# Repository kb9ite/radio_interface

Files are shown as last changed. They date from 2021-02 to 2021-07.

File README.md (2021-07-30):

# Radio Interface
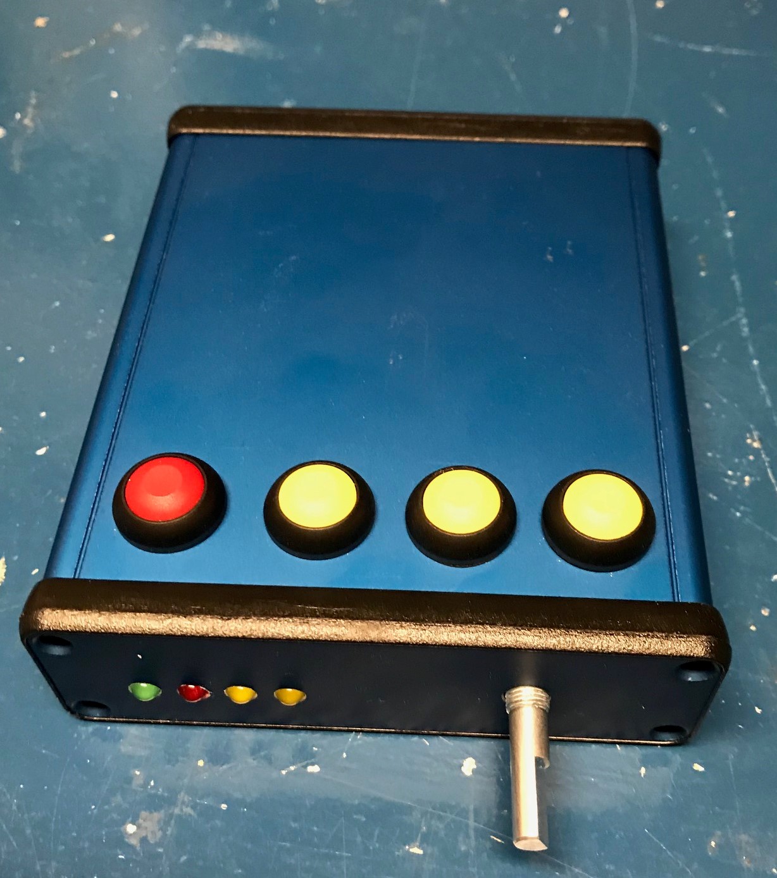
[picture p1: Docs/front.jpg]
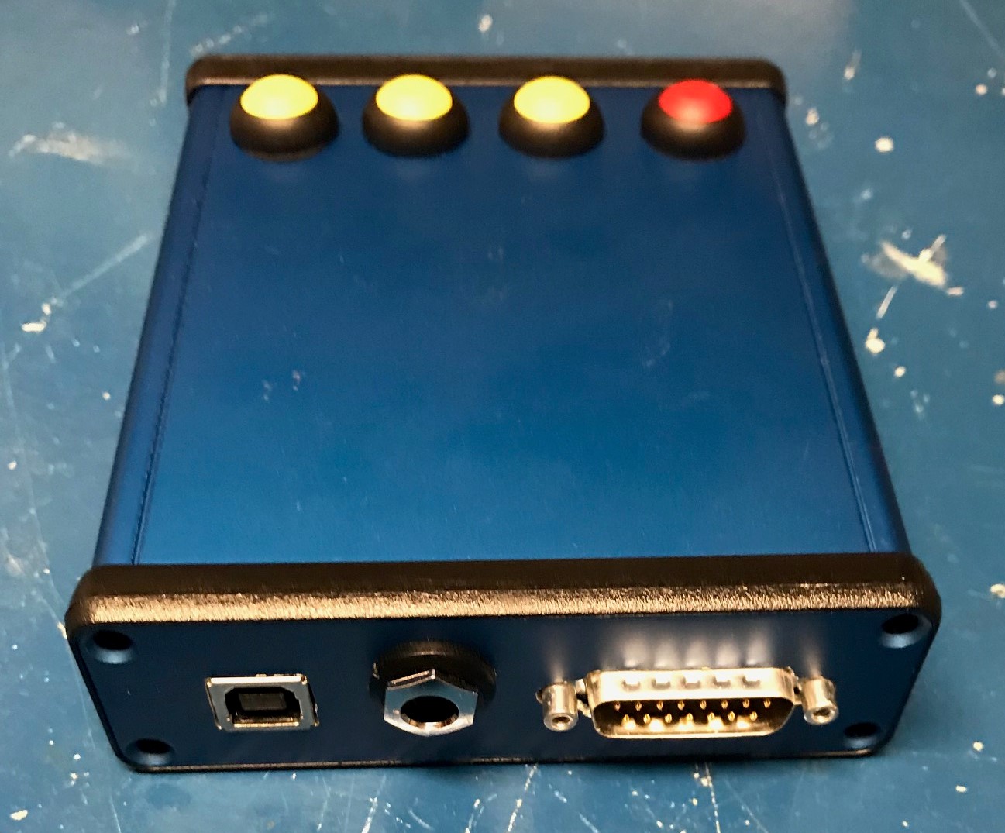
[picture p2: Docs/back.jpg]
  

## Introduction
I've been a ham for a while, growing up the son of a ham, I had a pretty nice setup readily available.  After some time away from the hobby I found myself getting back into it and starting to put together my own station.  I quickly realized I was going to want to interface the radio with the computer.  As I started to breakdown my needs I came up with the following:

 - Rx and Tx audio to run digital modes
 - PTT so I could avoid using Vox and transmitting computer sounds I shouldn't
 - FSK to dabble in RTTY
 - CW Key thinking I might learn morse code again
 - Serial so that I could get the bandmap working on my PC

Taking a look around there are a number of good options for off the shelf interfaces, although non had all the functionality I was looking for in one box.  Being a DIY kind of person (and frugal) and having some experience with PCB design and assembly I figured I would just build my own.  A little bit of searching around showed that there were single chip solutions for a USB sound card and I had already used USB to serial devices in previous projects.  Armed with that information I set out looking for a design to build.  I figured surely someone has shared a design where they through a USB hub, USB audio codec and USB to serial adapter on a single PCB, right?  All of my searching produced nothing, so I decided to design one myself.

This project represents the results of that effort.  It is a single box solution that includes a sound card, 2 serial ports, a WinKeyer and galvanic isolation between the radio and PCB.
## Design
The general design philosophy I used was to try and make the design flexible to be adapted to other people's uses without requiring PCB changes.  To that end there are some optional components and a jumper area for some configuring.

Starting with the computer end, the design includes a 3 port USB hub to allow a single USB connection to the PC.  This connects the audio coded (TI PCM2903C) and 2 USB to serial chips (FTDI FT231XS).

One of the serial ports is setup for communication with the radio.  A pair of digital isolators are used to provide galvanically isolated TTL level Rx, Tx, RTS and CTS signals.  If this is the desired output some jumpers can be installed and these signals will be at the radio connector.  If RS232 levels are needed there is provision for an RS232 level shifter or if an ICOM CI-V interface is needed there is space for a simple transistor to provide the open collector style single wire serial.  The polarity of the inputs/outputs on the serial interface can be changed using the FT_Prog utility from FTDI.

The second serial port allows control of an onboard WinKeyer3 IC from K1EL.  All the required peripherals to support the WinKeyer are included on board (speed pot, push button inputs and side tone speaker).

The audio support mono input/output.  By populating/depopulating a few parts the input/output channel can be changed as the PCM2903 is a stereo codec.  I built mine to just use left channel audio.  From the codec there is a second order low pass filter and then transformer for isolation.  On the radio side of the audio is provision for a fixed pad and a trimmer.  The fixed pad is intended to be used if a significant level shift is needed from line to mic or speaker to line levels.  The trimmer allows fine tuning of the levels to match the transceiver and computer.  The trimmer pots are inside the device so they are intended for a set it and forget it setup and regular fine tuning can be done either with radio controls (if available) or with the volume controls on the computer.

The outputs section supports up to 4 control outputs to the radio.  These can be used for whatever is desired (PTT, Key, FSK,...).  The outputs are designed to support either a optocoupler or reed relay for isolation of the outputs.  There is also the option of a front panel LED for each output to allow monitoring the output statuses.  The function of each output is selected through installing jumpers in the jumper area.  Signals available for the outputs include:

- All WinKeyer outputs (PTT1/2, Key 1/2)
- Both Serial Port (Tx, Rx, RTS, CTS, DTR)

The idea here is to make it easy for someone to build the box to his/her needs when building the device  by installing the desired set of jumpers on the prototyping connector.
|  |  |  |  |  |  |  |  |  |
|--|--|--|--|--|--|--|--|--|
|3-CAT_CTS|6-Out2Ctrl|9-Out4Ctrl|12-P1Key|15-P2PTT|18-Ser1_DTR|21-Ser1_CTS|24-Ser2_DTR|27-3.3V
|2-OutCom|5-CAT_Tx|8-Out3Ctrl|11-P1PTT|14-P2Key|17-Ser1_RTS|20-Ser2_Tx|23-Ser2_RTS|26-5V
|1-CAT_RTS|4-CAT_Rx|7-GND|10-Out1CTRL|13-Ser1_Tx|16-Ser1_Rx|19-Ser2_Rx|22-Ser2_CTS|25-GND

The interface to the radio is done with a DB15 connector.  The pinout is as follows:

 1. Rx Audio -
 2. Tx Audio -
 3. CAT_Rx
 4. CAT_CTS
 5. Out4
 6. Out3
 7. Out2
 8. Out1
 9. Rx Audio +
 10. Tx Audio +
 11. CAT_Tx
 12. CAT_RTS
 13. Out Common
 14. Out Common
 15. Out Common
 
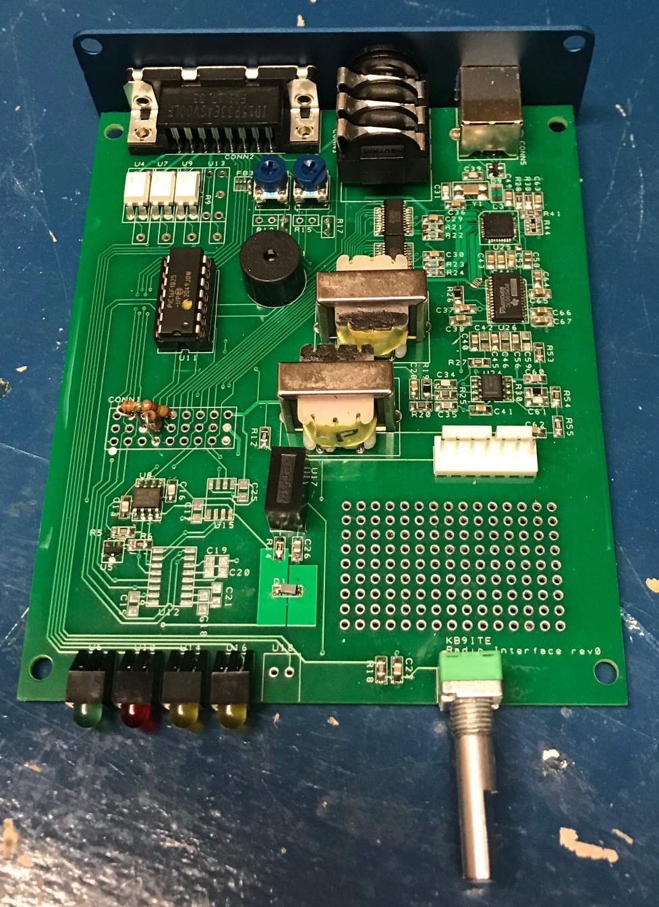
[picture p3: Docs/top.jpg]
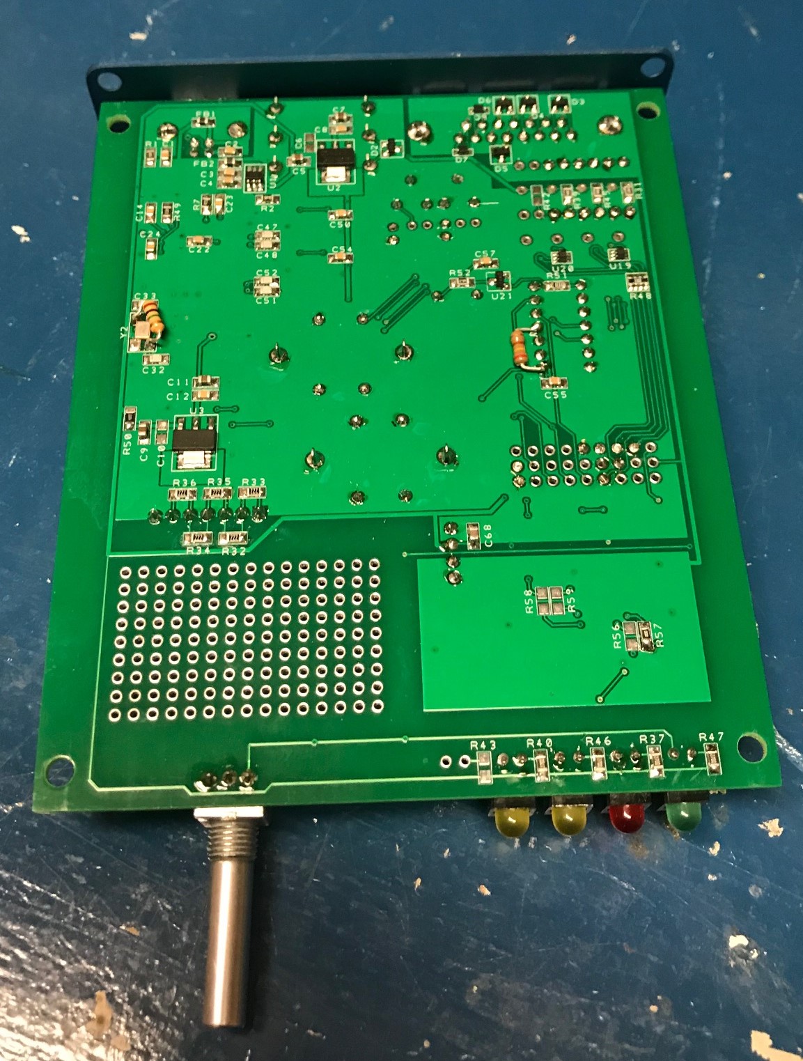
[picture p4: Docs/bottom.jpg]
   

## Tools
The schematic capture and PCB layout is all done with DesignSpark 9.0.
There is one device on the PCB that must be soldered with a hot air or reflowed and a couple of other that are easier that way, but could be done by hand.  Other than that most devices can be soldered by hand.

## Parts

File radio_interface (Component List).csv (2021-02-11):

Component List
--------------
Report Written: | Wednesday, February 10, 2021
Project Path: | C:\projects\radio_interface\DesignSpark\radio_interface.prj
Design Path: | C:\projects\radio_interface\DesignSpark\radio_interface.pcb
Design Title:
Created: | 1/28/2021 1:03:58 PM
Last Saved: | 2/10/2021 9:54:25 AM
Editing Time: | 19019 min
Units: | thou (precision 0)
Ref Name | Value | Manufacturer | Manufacturer Part Number | Digikey Number | Mouser Value
--------------------------------------------------------------------------------------------
C1 | 0.1u |  |  | 478-10836-1-ND | 581-08055C104KAT4A
C2 | 1n |  |  | 732-7813-1-ND | 187-CL21B102KBCNNNC
C3 | 1n |  |  | 732-7813-1-ND | 187-CL21B102KBCNNNC
C4 | 1u |  |  | 1276-1066-1-ND | 187-CL21B105KOFNNNG
C5 | 4.7u |  |  | 1276-6464-1-ND | 791-0805B475K6R3CT
C7 | 4.7u |  |  | 1276-6464-1-ND | 791-0805B475K6R3CT
C8 | 1n |  |  | 732-7813-1-ND | 187-CL21B102KBCNNNC
C9 | 4.7u |  |  | 1276-6464-1-ND | 791-0805B475K6R3CT
C11 | 4.7u |  |  | 1276-6464-1-ND | 791-0805B475K6R3CT
C12 | 1n |  |  | 732-7813-1-ND | 187-CL21B102KBCNNNC
C13 | 0.1u |  |  | 478-10836-1-ND | 581-08055C104KAT4A
C14 | 0.1u |  |  | 478-10836-1-ND | 581-08055C104KAT4A
C15 | 1u |  |  | 1276-1066-1-ND | 187-CL21B105KOFNNNG
C16 | 0.1u |  |  | 478-10836-1-ND | 581-08055C104KAT4A
C17 | 0.1u |  |  | 478-10836-1-ND | 581-08055C104KAT4A
C18 | 1u |  |  | 1276-1066-1-ND | 187-CL21B105KOFNNNG
C19 | 1u |  |  | 1276-1066-1-ND | 187-CL21B105KOFNNNG
C20 | 1u |  |  | 1276-1066-1-ND | 187-CL21B105KOFNNNG
C21 | 1u |  |  | 1276-1066-1-ND | 187-CL21B105KOFNNNG
C22 | 0.1u |  |  | 478-10836-1-ND | 581-08055C104KAT4A
C23 | 0.1u |  |  | 478-10836-1-ND | 581-08055C104KAT4A
C24 | 0.1u |  |  | 478-10836-1-ND | 581-08055C104KAT4A
C25 | 0.1u |  |  | 478-10836-1-ND | 581-08055C104KAT4A
C26 | 4.7u |  |  | 1276-6464-1-ND | 791-0805B475K6R3CT
C27 | 4.7n |  |  | 732-8037-1-ND | 710-885012207037
C28 | 10u |  |  | 1276-1096-1-ND | 187-CL21A106KQFNNNG
C29 | 0.1u |  |  | 478-10836-1-ND | 581-08055C104KAT4A
C30 | 0.1u |  |  | 478-10836-1-ND | 581-08055C104KAT4A
C31 | 12p |  |  | 311-1100-1-ND | 603-CC805JRNPO9BN120
C32 | 12p |  |  | 311-1100-1-ND | 603-CC805JRNPO9BN120
C33 | 12p |  |  | 311-1100-1-ND | 603-CC805JRNPO9BN120
C34 | 330p |  |  | 399-1130-1-ND | 80-C0805C331J5G
C35 | 1.8n |  |  | 445-5752-1-ND | 810-C2012C0G1H182J-1
C36 | 0.1u |  |  | 478-10836-1-ND | 581-08055C104KAT4A
C37 | 10u |  |  | 1276-1096-1-ND | 187-CL21A106KQFNNNG
C38 | 10u |  |  | 1276-1096-1-ND | 187-CL21A106KQFNNNG
C39 | 12p |  |  | 311-1100-1-ND | 603-CC805JRNPO9BN120
C40 | 10u |  |  | 1276-1096-1-ND | 187-CL21A106KQFNNNG
C41 | 10u |  |  | 1276-1096-1-ND | 187-CL21A106KQFNNNG
C43 | 0.1u |  |  | 478-10836-1-ND | 581-08055C104KAT4A
C44 | 0.1u |  |  | 478-10836-1-ND | 581-08055C104KAT4A
C45 | 10u |  |  | 1276-1096-1-ND | 187-CL21A106KQFNNNG
C47 | 47p |  |  | 311-1107-1-ND | 710-885012007014
C48 | 47p |  |  | 311-1107-1-ND | 710-885012007014
C49 | 0.1u |  |  | 478-10836-1-ND | 581-08055C104KAT4A
C50 | 0.1u |  |  | 478-10836-1-ND | 581-08055C104KAT4A
C51 | 47p |  |  | 311-1107-1-ND | 710-885012007014
C52 | 47p |  |  | 311-1107-1-ND | 710-885012007014
C53 | 0.1u |  |  | 478-10836-1-ND | 581-08055C104KAT4A
C54 | 0.1u |  |  | 478-10836-1-ND | 581-08055C104KAT4A
C55 | 0.1u |  |  | 478-10836-1-ND | 581-08055C104KAT4A
C56 | 10u |  |  | 1276-1096-1-ND | 187-CL21A106KQFNNNG
C57 | 0.1u |  |  | 478-10836-1-ND | 581-08055C104KAT4A
C58 | 4.7u |  |  | 1276-6464-1-ND | 791-0805B475K6R3CT
C60 | 1.8n |  |  | 445-5752-1-ND | 810-C2012C0G1H182J-1
C61 | 330p |  |  | 399-1130-1-ND | 80-C0805C331J5G
C62 | 10u |  |  | 1276-1096-1-ND | 187-CL21A106KQFNNNG
C63 | 0.1u |  |  | 478-10836-1-ND | 581-08055C104KAT4A
C64 | 10u |  |  | 1276-1096-1-ND | 187-CL21A106KQFNNNG
C65 | 10u |  |  | 1276-1096-1-ND | 187-CL21A106KQFNNNG
C66 | 10u |  |  | 1276-1096-1-ND | 187-CL21A106KQFNNNG
C67 | 10u |  |  | 1276-1096-1-ND | 187-CL21A106KQFNNNG
C68 | 4.7u |  |  | 1276-6464-1-ND | 791-0805B475K6R3CT
CONN2 |  |  | A-DF 15 A/KG-T2S | AE10929-ND | 649-ID15P33E4GV00LF
CONN3 |  |  | NMJ6HCD3 |  | 568-NMJ6HCD3
CONN4 |  |  |  |  | 538-22-23-2071
CONN5 |  |  | UJ2-BH-2-TH | 102-5884-ND | 490-UJ2-BH-2-TH
D1 | 5.1V |  |  |  | 771-PDZ5.1BGWX
D2 |  |  |  |  | 750-CPDT-5V0U
D3 |  |  |  |  | 750-CPDT-5V0U
D4 |  |  |  |  | 750-CPDT-5V0U
D5 |  |  |  |  | 750-CPDT-5V0U
D6 |  |  |  |  | 750-CPDT-5V0U
D7 |  |  | DESD5V0U1BA-7 |  | 621-DESD5V0U1BA-7
D8 |  |  | DESD5V0U1BA-7 |  | 621-DESD5V0U1BA-7
D9 |  |  | CM1213A-02SR | CM1213A-02SROSCT-ND | 748-CM1213A-02SR
FB1 |  |  |  | 490-1054-1-ND | 81-BLM21P221SG
FB2 |  |  |  | 490-1054-1-ND | 81-BLM21P221SG
FB3 |  |  | BK32164W241-T |  | 963-BK32164W241-T
L1 |  |  |  |  | 42TM018-RC
L2 |  |  |  |  | 42TM018-RC
R1 | 330 |  |  | A106061CT-ND | 754-RR1220P-331D
R2 | 604 |  |  | 311-604CRCT-ND | 603-RC0805FR-07604RL
R3 |  |  | 3570-1331-053 | 1835-1117-ND
R4 |  |  | 3570-1331-053 | 1835-1117-ND
R5 | 100k |  |  | 311-100KARCT-ND | 667-ERJ-6ENF1003V
R6 | 4.7k |  |  | A106065CT-ND | 71-CRCW08054K70FKEAC
R7 | 47k |  |  | A130144CT-ND | 279-CRGCQ0805J47K
R8 |  |  | 3570-1331-053 | 1835-1117-ND
R9 |  |  | 3570-1331-053 | 1835-1117-ND
R10
R11 | 2k |  | 3306F-1-202 |  | 652-3306F-1-202
R12 | 4.7k |  |  | A106065CT-ND | 71-CRCW08054K70FKEAC
R13
R14 | 20 |  |  |  | 667-ERJ-6ENF20R0V
R15
R16 | 2k |  | 3306F-1-202 |  | 652-3306F-1-202
R17
R18 | 470 |  |  | A129745CT-ND | 279-CRGCQ0805F470R
R19 | 3.9k |  |  | A126369CT-ND | 71-CRCW08053K90FKEA
R20 | 12k |  |  | A129762CT-ND | 279-CRGCQ0805F12K
R21 | 27 |  |  | 2019-RK73H2ATTD27R0FCT-ND | 660-RK73H2ATTD27R0F
R22 | 27 |  |  | 2019-RK73H2ATTD27R0FCT-ND | 660-RK73H2ATTD27R0F
R23 | 27 |  |  | 2019-RK73H2ATTD27R0FCT-ND | 660-RK73H2ATTD27R0F
R24 | 27 |  |  | 2019-RK73H2ATTD27R0FCT-ND | 660-RK73H2ATTD27R0F
R25 | 12k |  |  | A129762CT-ND | 279-CRGCQ0805F12K
R27 | 100 |  |  | A129737CT-ND | 279-CRGCQ0805F100R
R28 | 100k |  |  | 311-100KARCT-ND | 667-ERJ-6ENF1003V
R29 | 10k |  | P091N-FC25BR10K |  | 858-P091N-FC25BR10K
R30 | 3.9k |  |  | A126369CT-ND | 71-CRCW08053K90FKEA
R31 | 180 |  |  | A126343CT-ND | 667-ERJ-6ENF1800V
R32 | 2.2k |  |  | A106060CT-ND | 754-RR1220P-222D
R33 | 2.2k |  |  | A106060CT-ND | 754-RR1220P-222D
R34 | 2.2k |  |  | A106060CT-ND | 754-RR1220P-222D
R35 | 2.2k |  |  | A106060CT-ND | 754-RR1220P-222D
R36 | 2.2k |  |  | A106060CT-ND | 754-RR1220P-222D
R37 | 270 |  |  | A129742CT-ND | 279-CRGCQ0805F270R
R38 | 100k |  |  | 311-100KARCT-ND | 667-ERJ-6ENF1003V
R39 | 180 |  |  | A126343CT-ND | 667-ERJ-6ENF1800V
R40 | 270 |  |  | A129742CT-ND | 279-CRGCQ0805F270R
R41 | 100k |  |  | 311-100KARCT-ND | 667-ERJ-6ENF1003V
R42 | 180 |  |  | A126343CT-ND | 667-ERJ-6ENF1800V
R43 | 270 |  |  | A129742CT-ND | 279-CRGCQ0805F270R
R44 | 47k |  |  | Y9473CT-ND | 667-EXB-38V473JV
R45 | 180 |  |  | A126343CT-ND | 667-ERJ-6ENF1800V
R46 | 270 |  |  | A129742CT-ND | 279-CRGCQ0805F270R
R47 | 270 |  |  | A129742CT-ND | 279-CRGCQ0805F270R
R48 | 1k |  |  | Y9102CT-ND | 667-EXB-38V102JV
R49 | 47k |  |  | A130144CT-ND | 279-CRGCQ0805J47K
R50 | 4.7 |  |  |  | 71-RCG08054R70JNEA
R51 | 1k |  |  |  | 667-EXB-38V102JV
R52 | 68 |  |  |  | 667-ERJ-6ENF68R0V
R53 | 12k |  |  | A129762CT-ND | 279-CRGCQ0805F12K
R54 | 12k |  |  | A129762CT-ND | 279-CRGCQ0805F12K
R55 | 100 |  |  | A129737CT-ND | 279-CRGCQ0805F100R
SP1 |  |  | AT-1224-TWT-5V-R |  | 665-AT1224TWT5VR
U1 |  |  | MIC2009A-1YM6-TR |  | 998-MIC2009A-1YM6TR
U2 | 3.3V |  | AP2114H-3.3TRG1 | AP2114H-3.3TRG1DICT-ND | 621-AP2114H-3.3TRG1
U3 | 3.3V |  | AP2114H-3.3TRG1 | AP2114H-3.3TRG1DICT-ND | 621-AP2114H-3.3TRG1
U4 |  |  | 140816141310 | 732-140816141310-ND | 710-140816141310
U5 |  |  |  |  | 771-MMBT3904T/R
U6 |  |  | Y: LTL-553-11 R: | Y: 160-1978-ND, R: 160-1976-ND, G: 160-1977-ND | G: 859-LTL-533-11, R: 859-LTL-523-11, Y: 859-LTL-553-11
U7 |  |  | 140816141310 | 732-140816141310-ND | 710-140816141310
U8 |  |  | SI8621BC-B-IS |  | 634-SI8621BC-B-IS
U9 |  |  | 140816141310 | 732-140816141310-ND | 710-140816141310
U10 |  |  | Y: LTL-553-11 R: | Y: 160-1978-ND, R: 160-1976-ND, G: 160-1977-ND | G: 859-LTL-533-11, R: 859-LTL-523-11, Y: 859-LTL-553-11
U11 |  |  | WinKeyer
U12 |  |  | MAX232DR |  | 595-MAX232DR
U13 |  |  | 140816141310 | 732-140816141310-ND | 710-140816141310
U14 |  |  | Y: LTL-553-11 R: | Y: 160-1978-ND, R: 160-1976-ND, G: 160-1977-ND | G: 859-LTL-533-11, R: 859-LTL-523-11, Y: 859-LTL-553-11
U15 |  |  | SI8621BC-B-IS |  | 634-SI8621BC-B-IS
U16 |  |  | Y: LTL-553-11 R: | Y: 160-1978-ND, R: 160-1976-ND, G: 160-1977-ND | G: 859-LTL-533-11, R: 859-LTL-523-11, Y: 859-LTL-553-11
U17 |  |  | RFM-0505S |  | 919-RFM-0505S
U18 |  |  | Y: LTL-553-11 R: | Y: 160-1978-ND, R: 160-1976-ND, G: 160-1977-ND | G: 859-LTL-533-11, R: 859-LTL-523-11, Y: 859-LTL-553-11
U19 |  |  | SSM6N7002KFU,LF | SSM6N7002KFULFCT-ND | 757-SSM6N7002KFULF
U20 |  |  | SSM6N7002KFU,LF | SSM6N7002KFULFCT-ND | 757-SSM6N7002KFULF
U21 |  |  |  |  | 771-MMBT3904T/R
U22 |  |  | FT231XS-U | 768-1156-5-ND | 895-FT231XS-U
U23 |  |  | FT231XS-U | 768-1156-5-ND | 895-FT231XS-U
U24 |  |  | OPA1678IDR | 296-47347-1-ND | 595-OPA1678IDR
U25 |  |  | USB2513B/M2 | USB2513B/M2-ND | 579-USB2513B/M2
U26 |  |  | PCM2903CDBR | 296-34778-1-ND | 595-PCM2903CDBR
Y1 | 24MHz |  |  | 2151-RH100-24.000-10-1010-TRCT-ND | 669-EA2532UA12-24
Y2 | 12MHz |  |  | 2151-RH100-12.000-10-2020-EXT-TRCT-ND | 520-120-10-33-AGLT
--------------------------------------------------------------------------------------------

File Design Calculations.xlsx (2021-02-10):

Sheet: USB2513 XTAL
C0 | 3.5 | pF
CL | 10 | pF
CB |  | pF
CS1 | 0 | pF
CS2 | 0 | pF
CXTAL |  | pF
C1 | 13 | pF
C2 | 13 | pF

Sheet: Vreg thermal
Vin | 5 | V
Vout | 3.3 | V
I | 0.5 | A
Ploss | 0.85 | W
Rjunc_case | 50.9 | C/W
Tamb | 40 | C
Tmax | 150 | C
Rheat_sink | 78.51176471
 |  |  | t = R*P

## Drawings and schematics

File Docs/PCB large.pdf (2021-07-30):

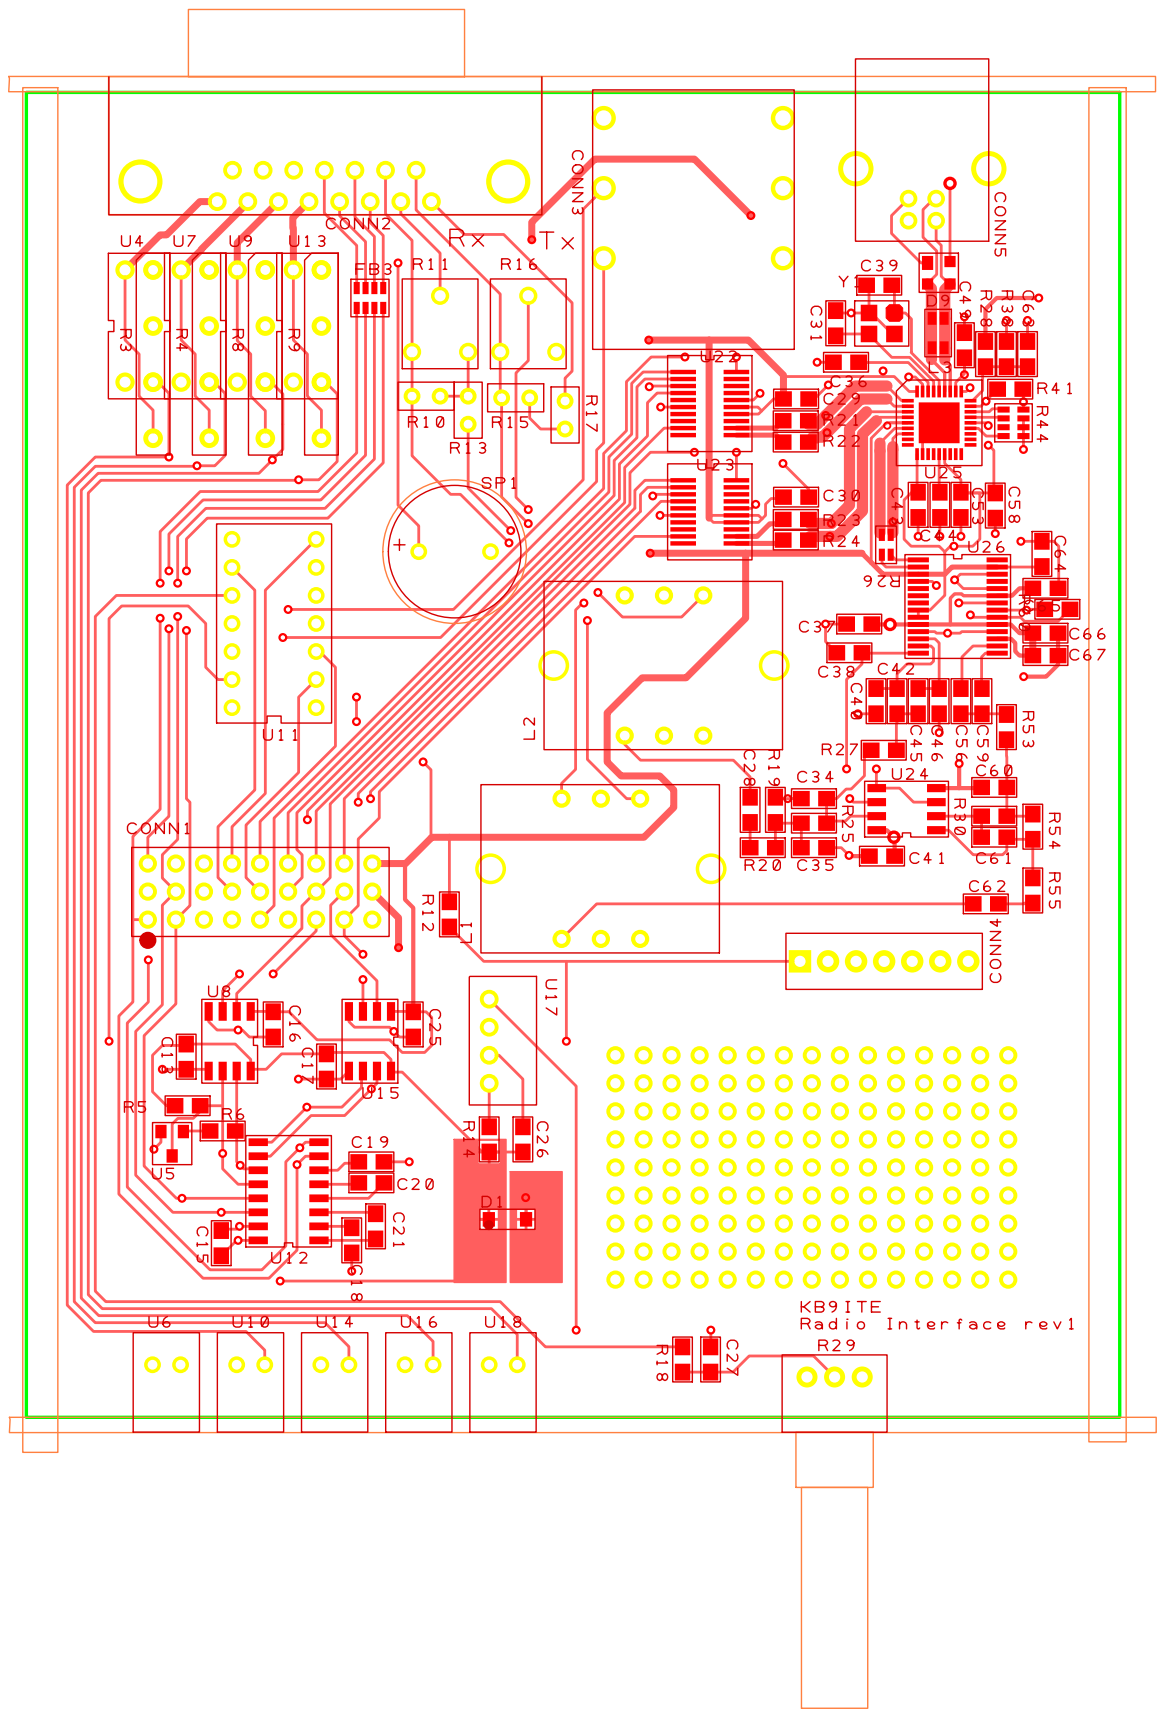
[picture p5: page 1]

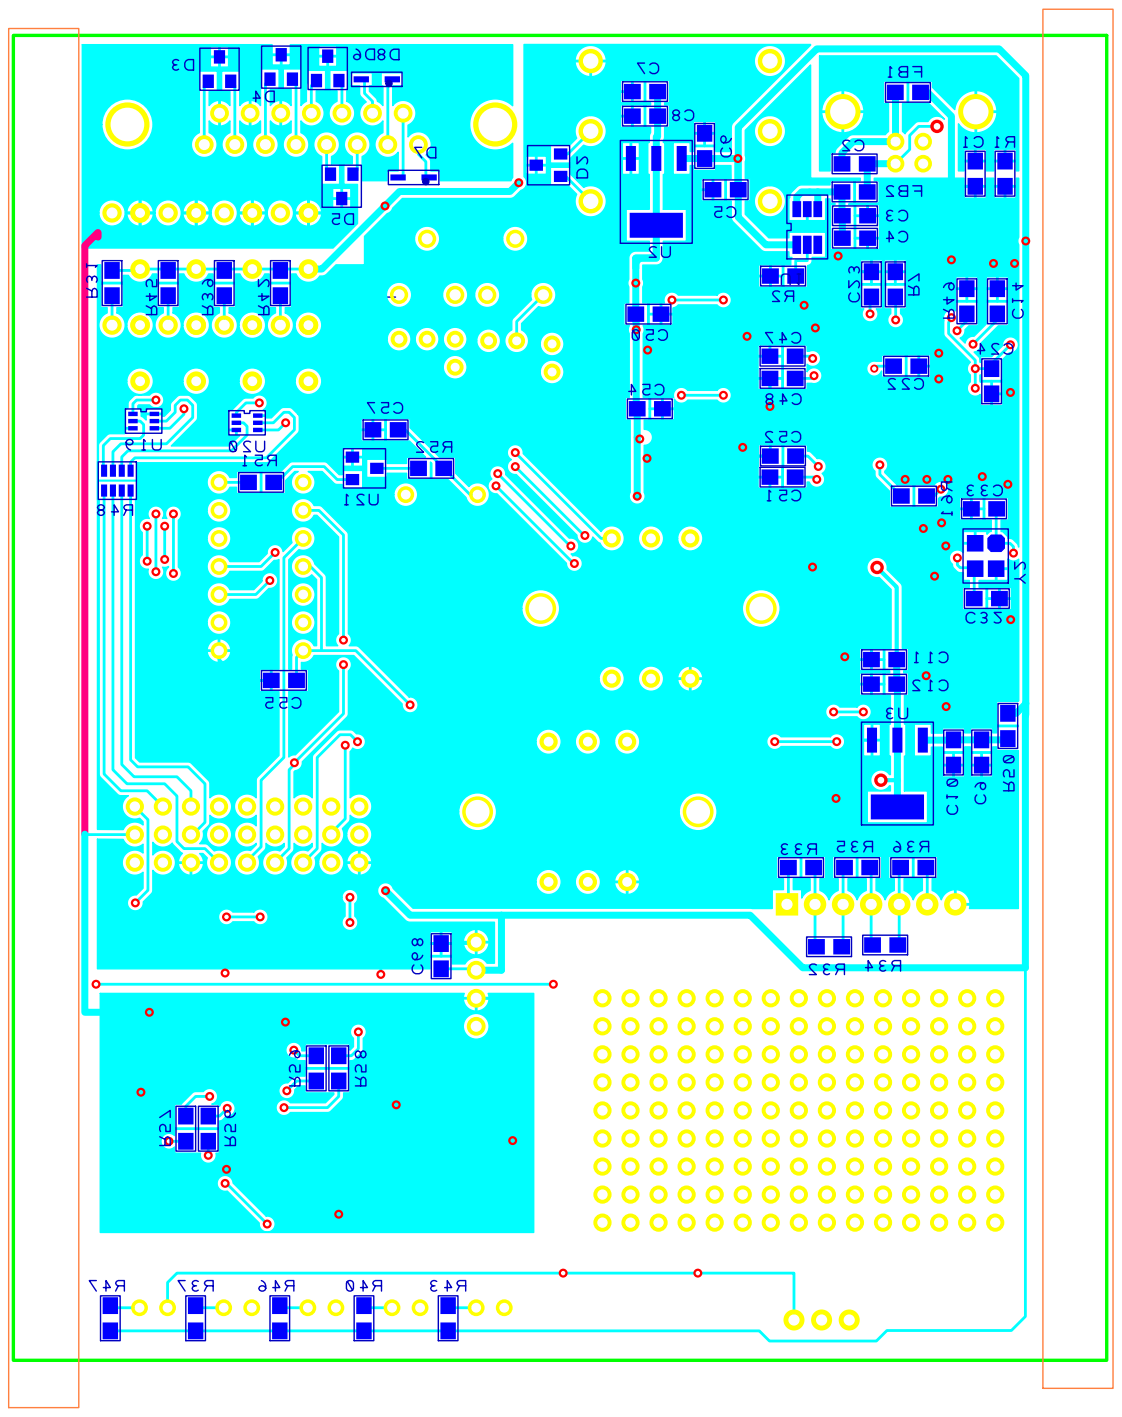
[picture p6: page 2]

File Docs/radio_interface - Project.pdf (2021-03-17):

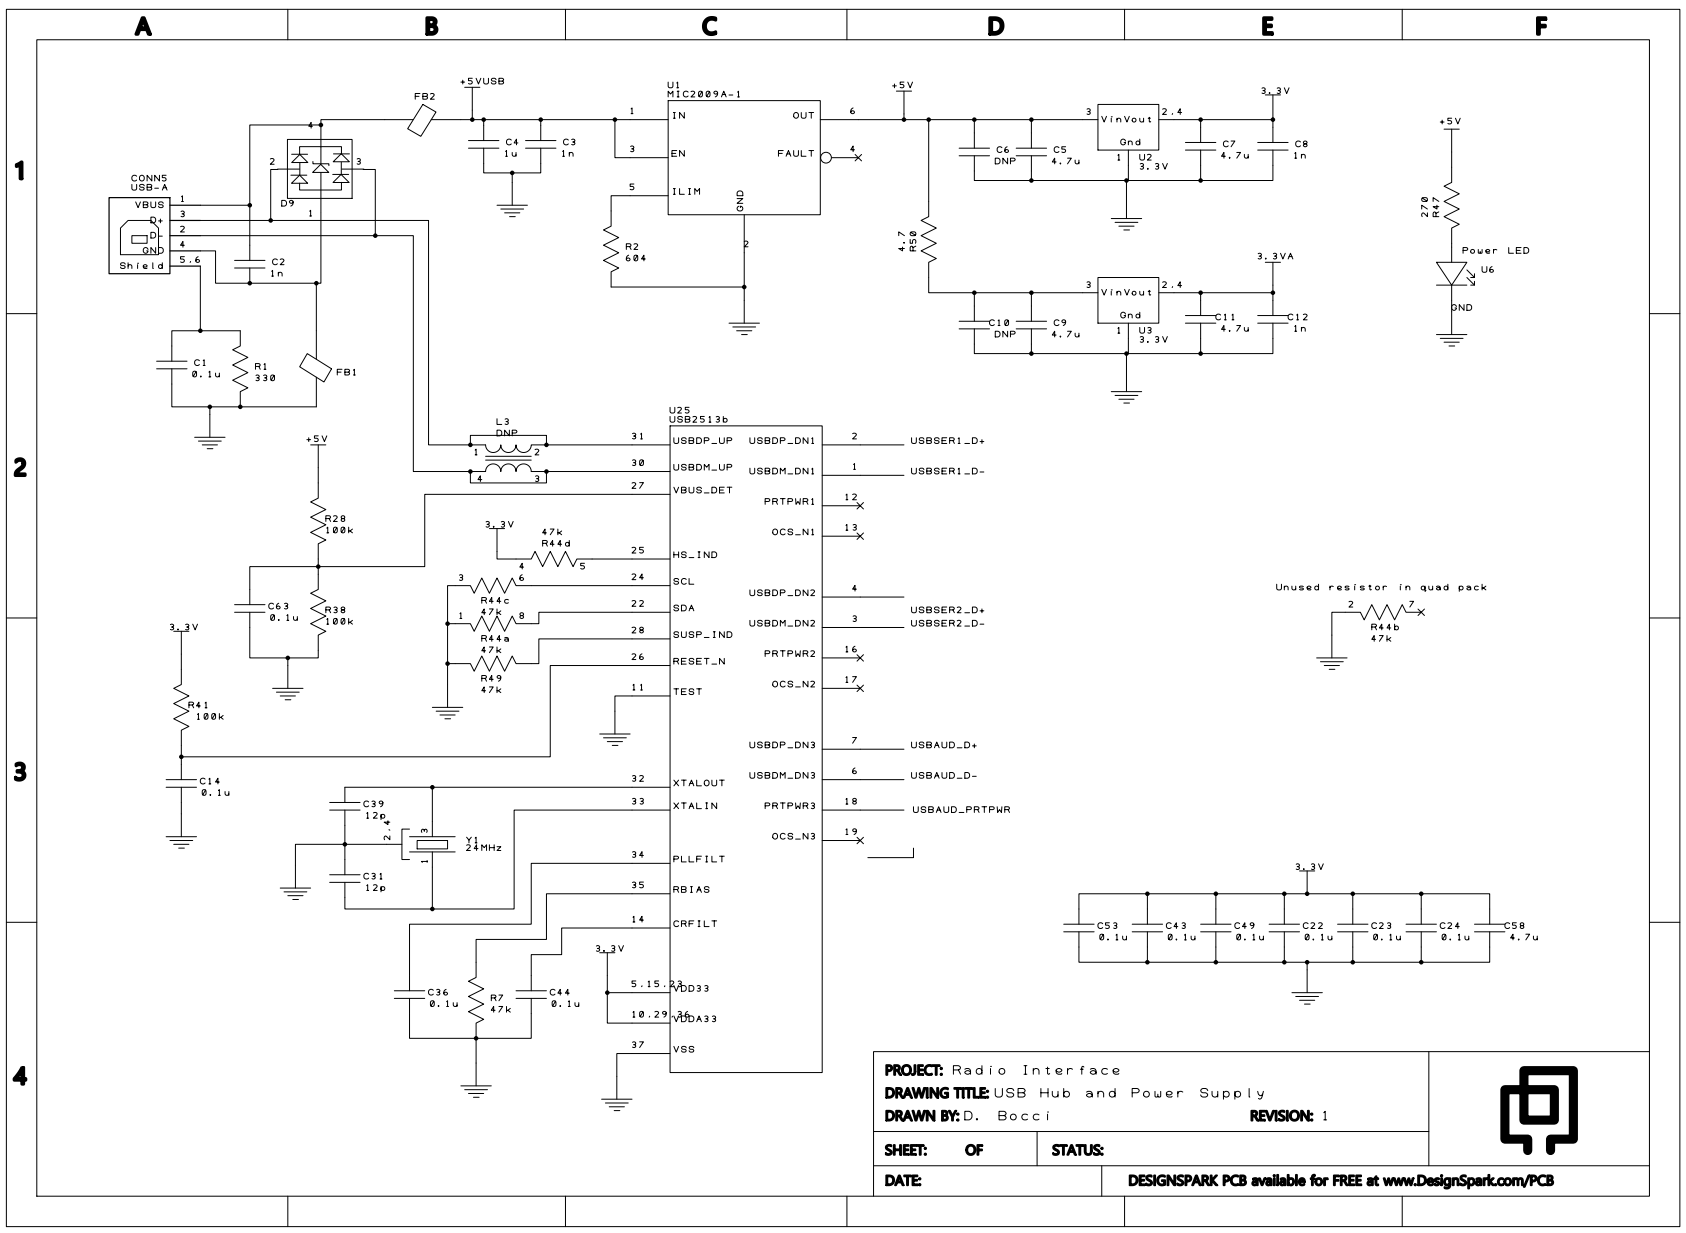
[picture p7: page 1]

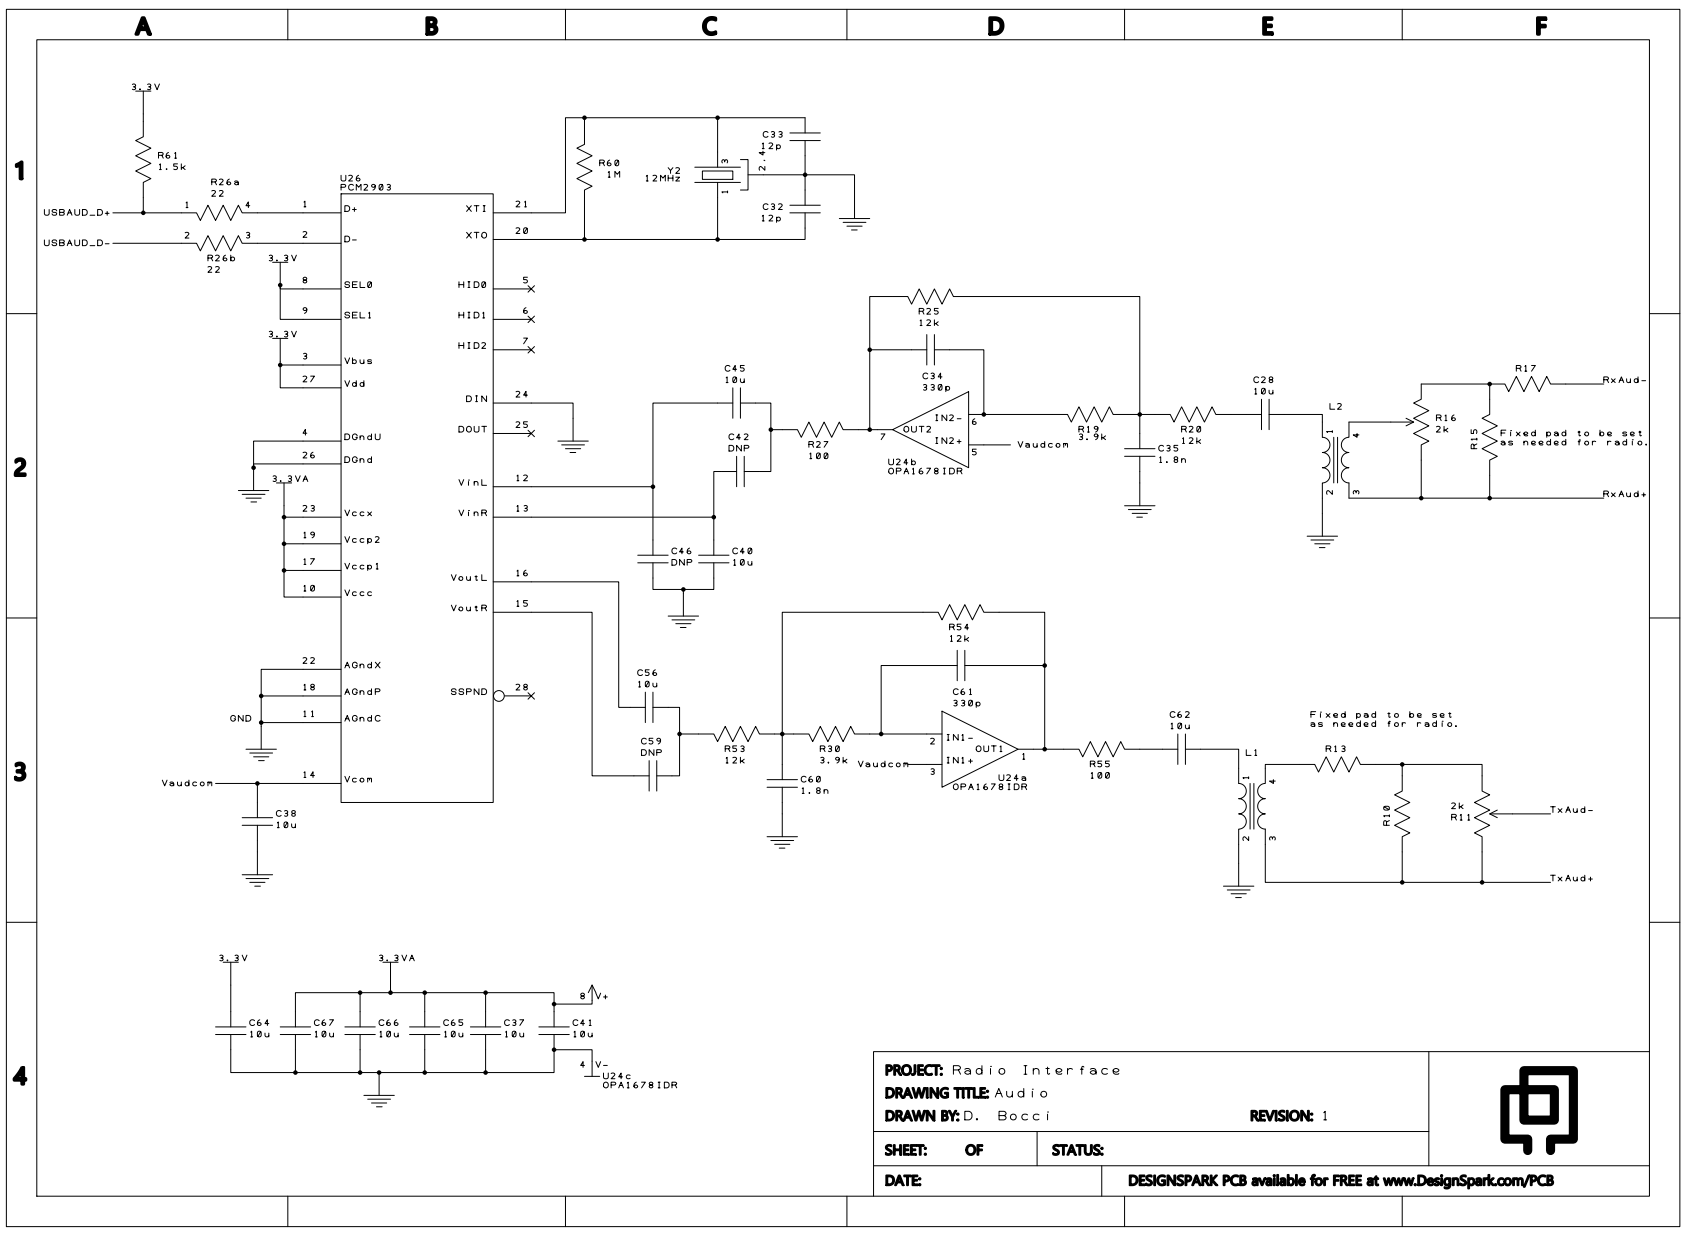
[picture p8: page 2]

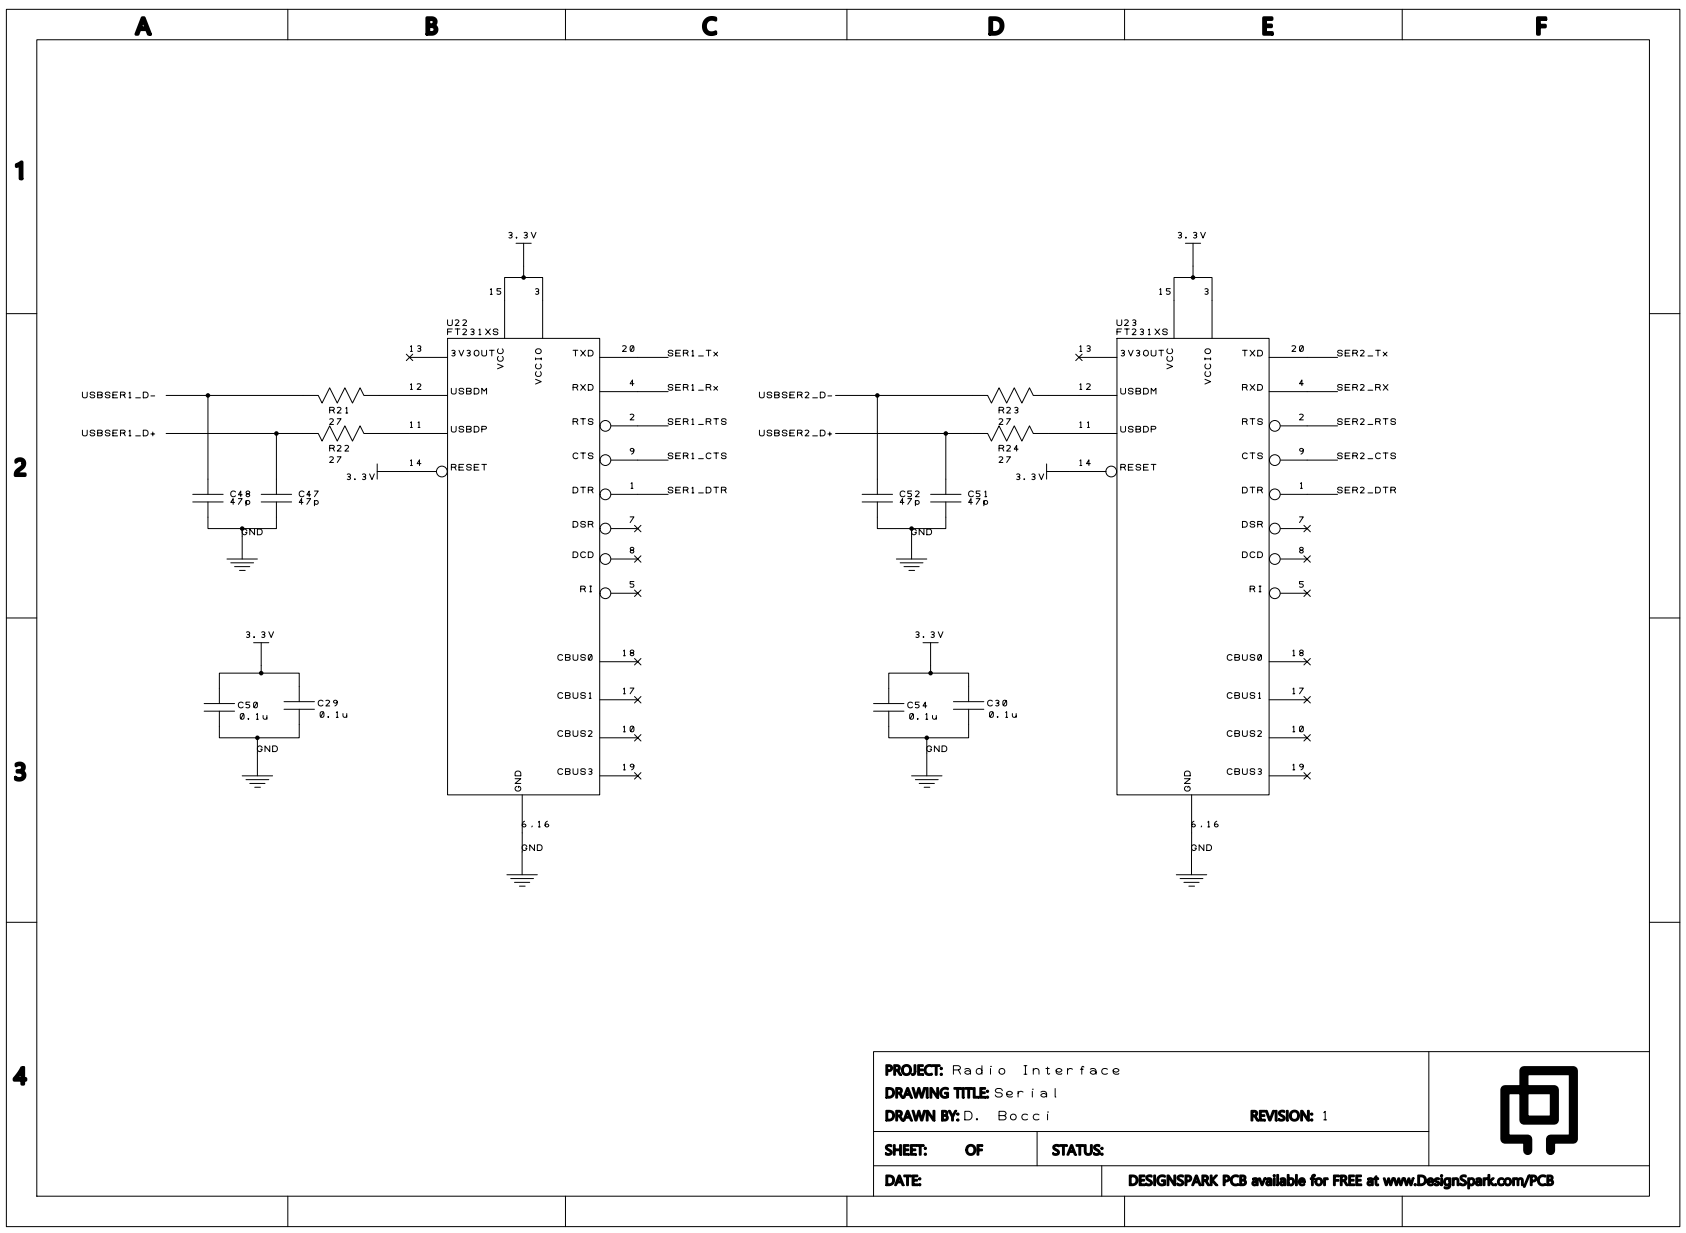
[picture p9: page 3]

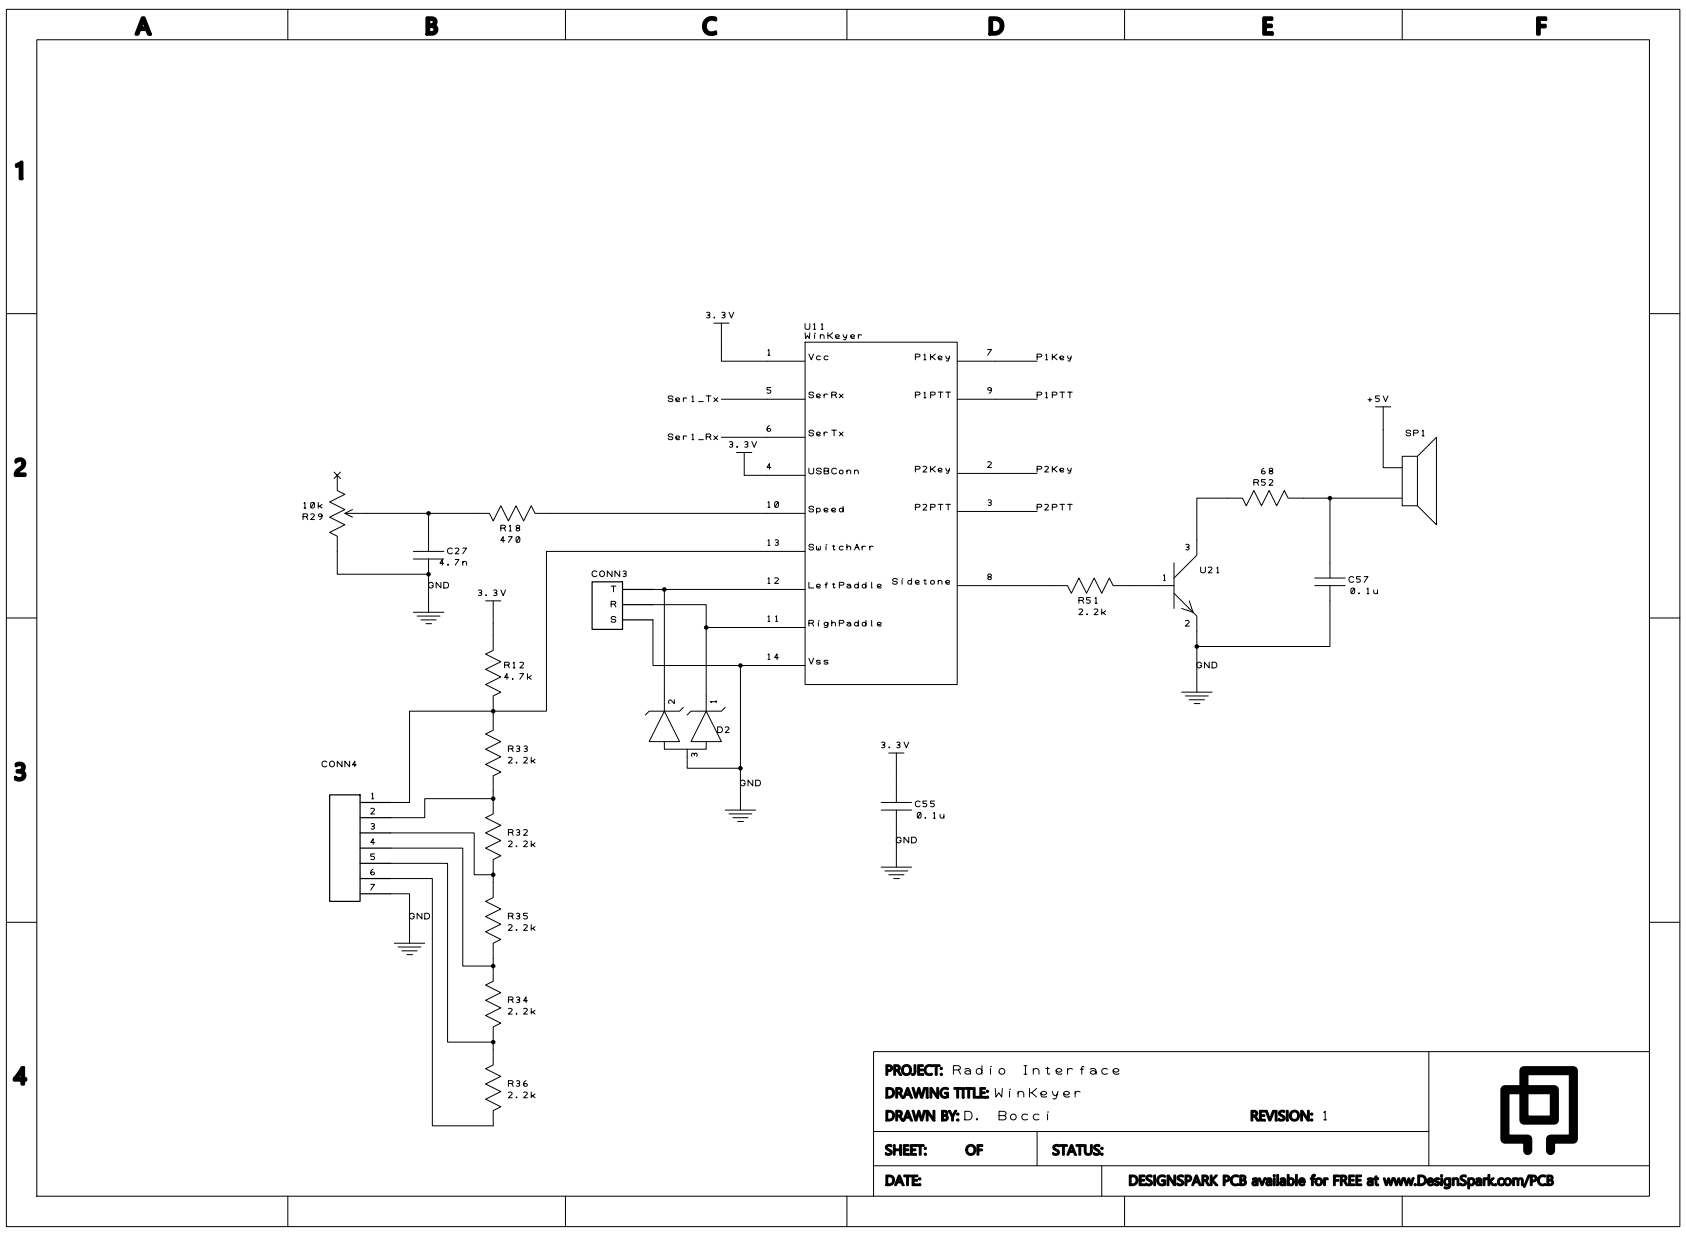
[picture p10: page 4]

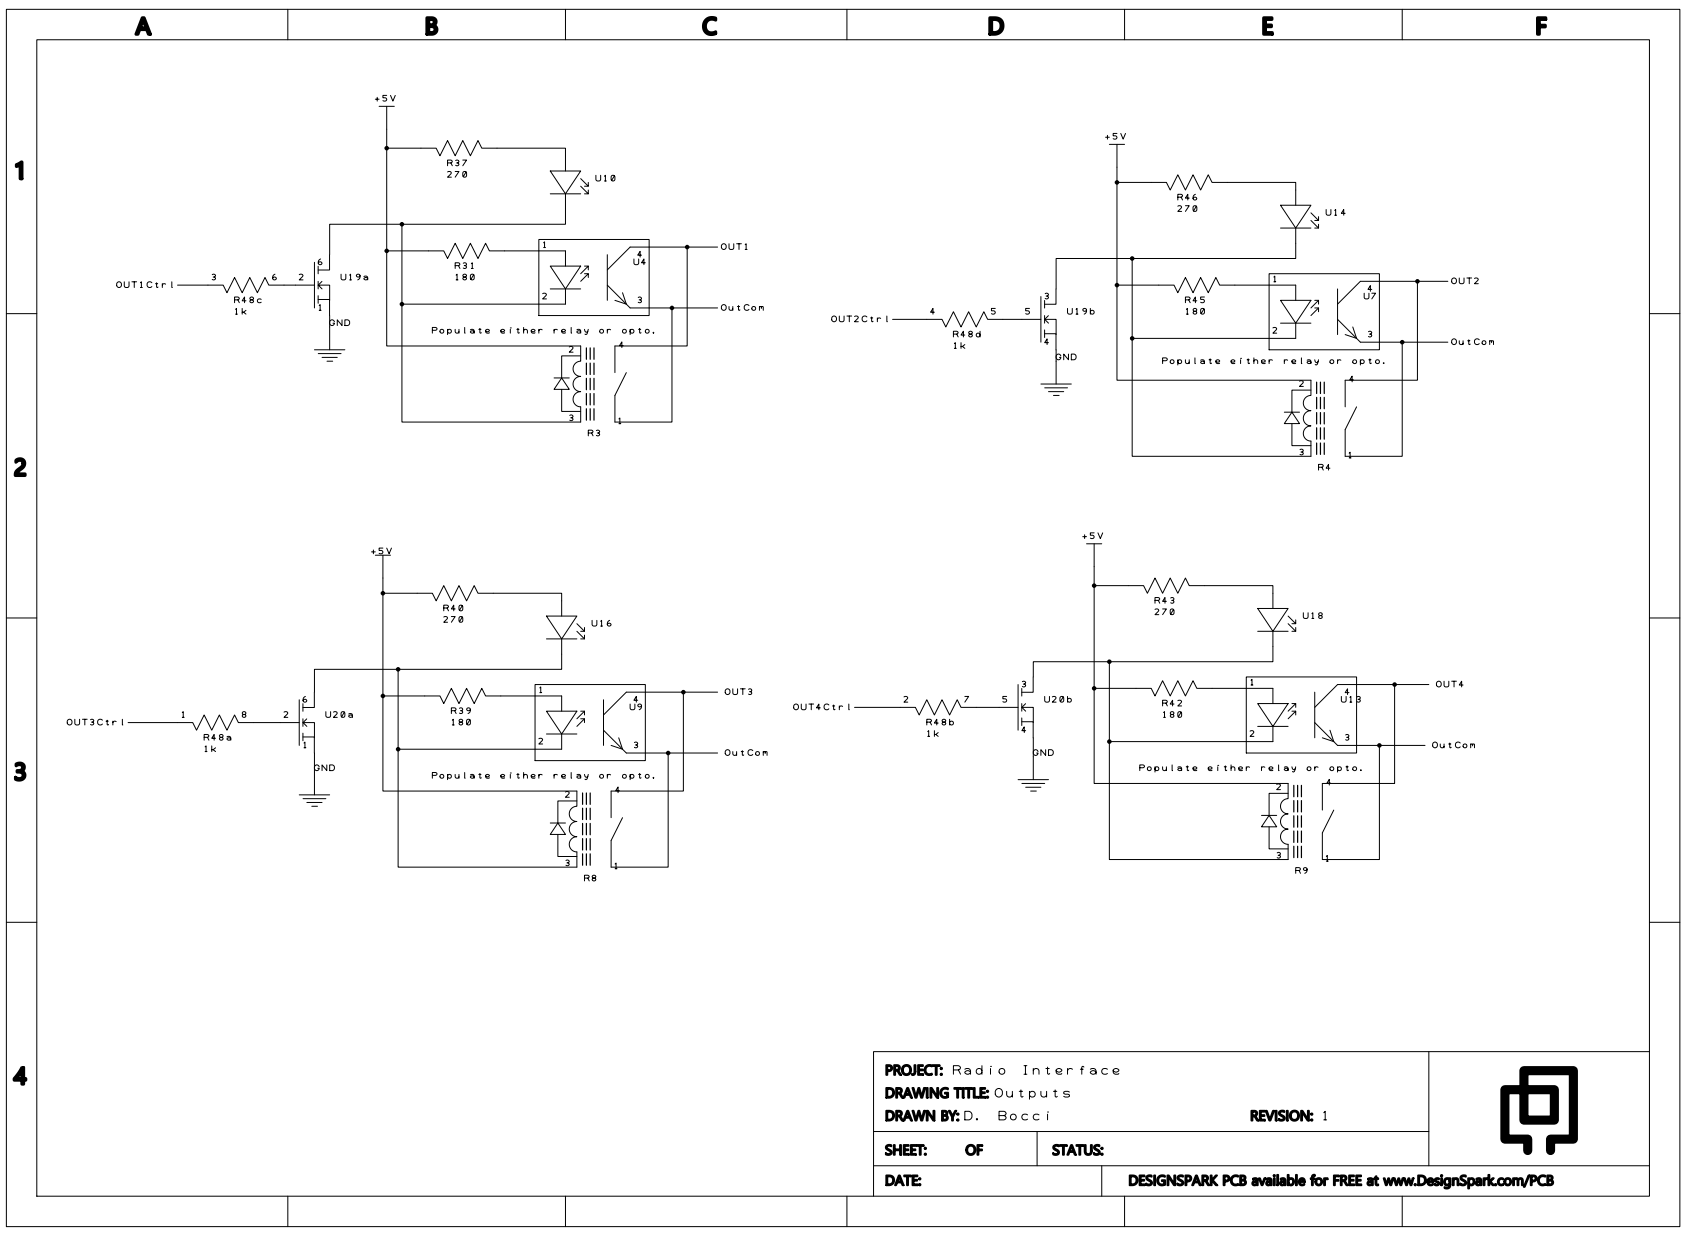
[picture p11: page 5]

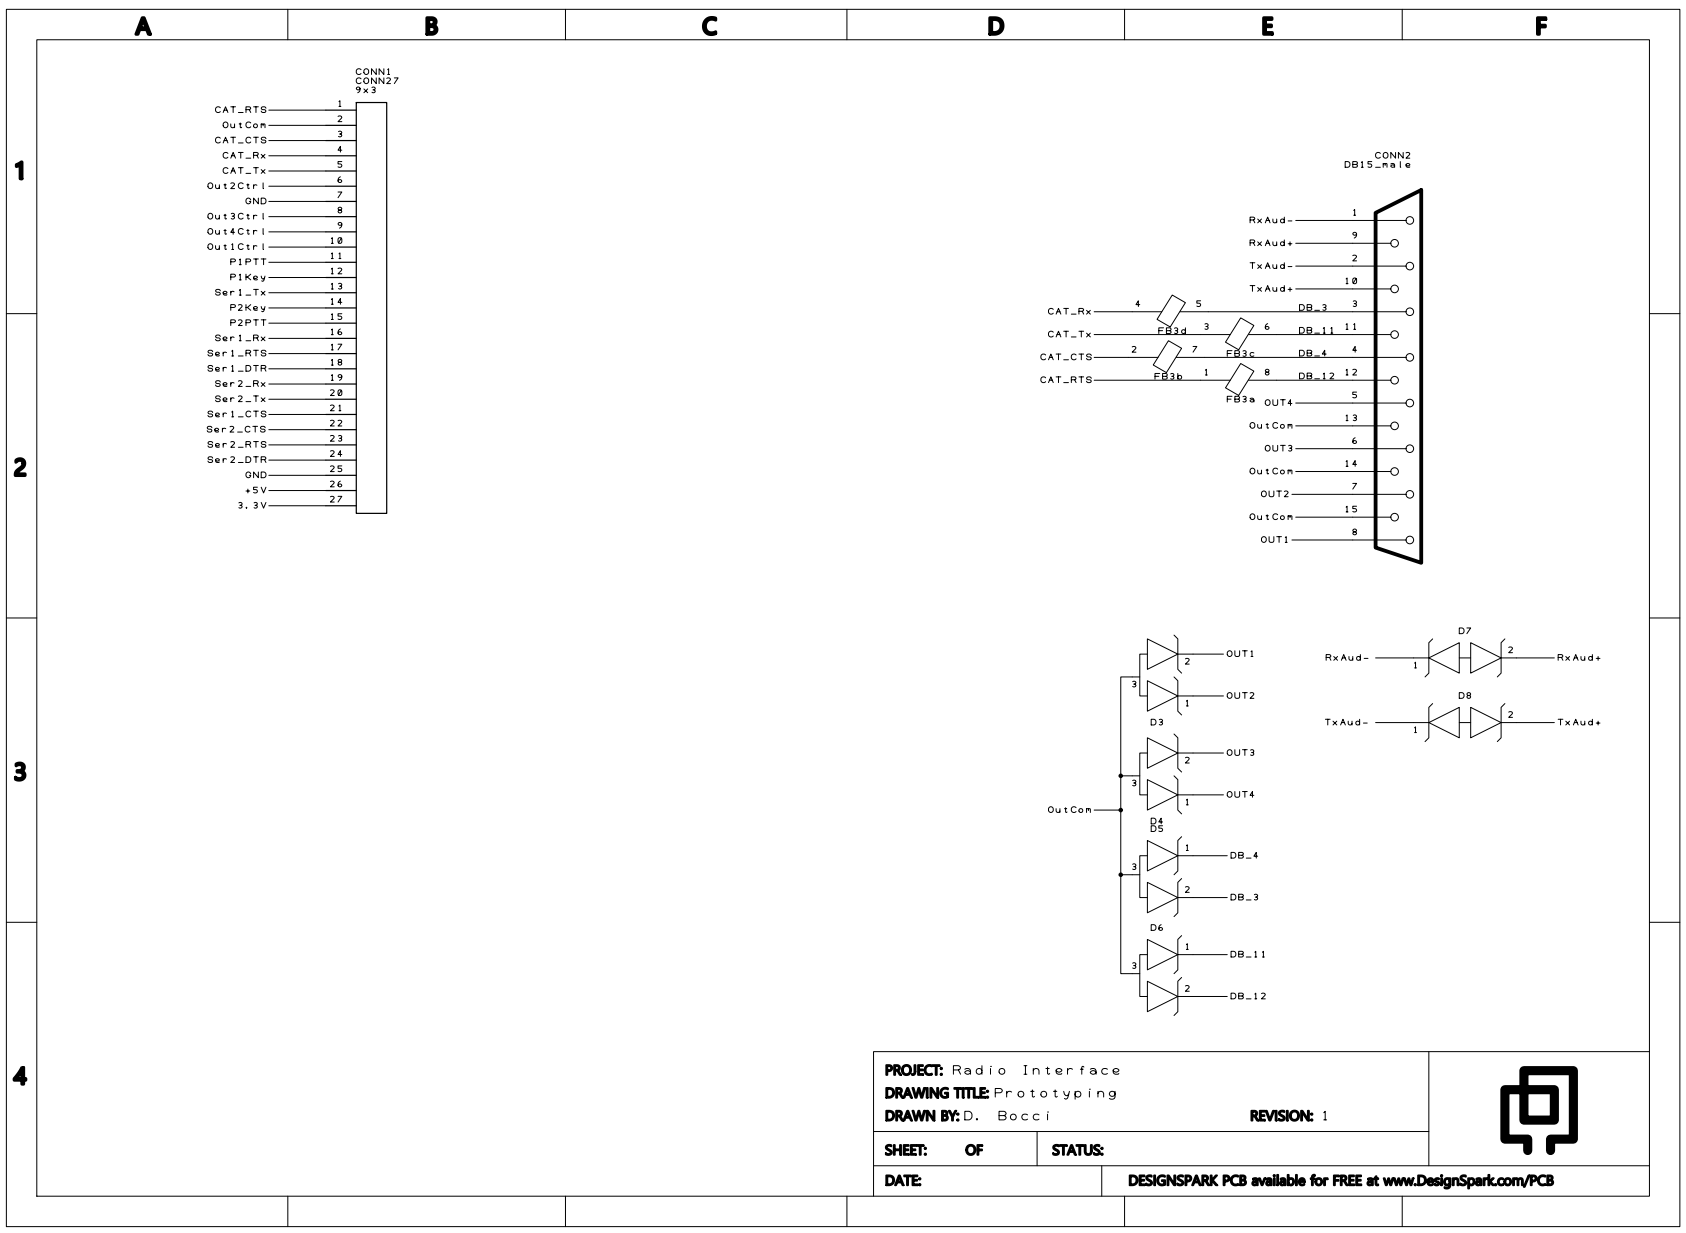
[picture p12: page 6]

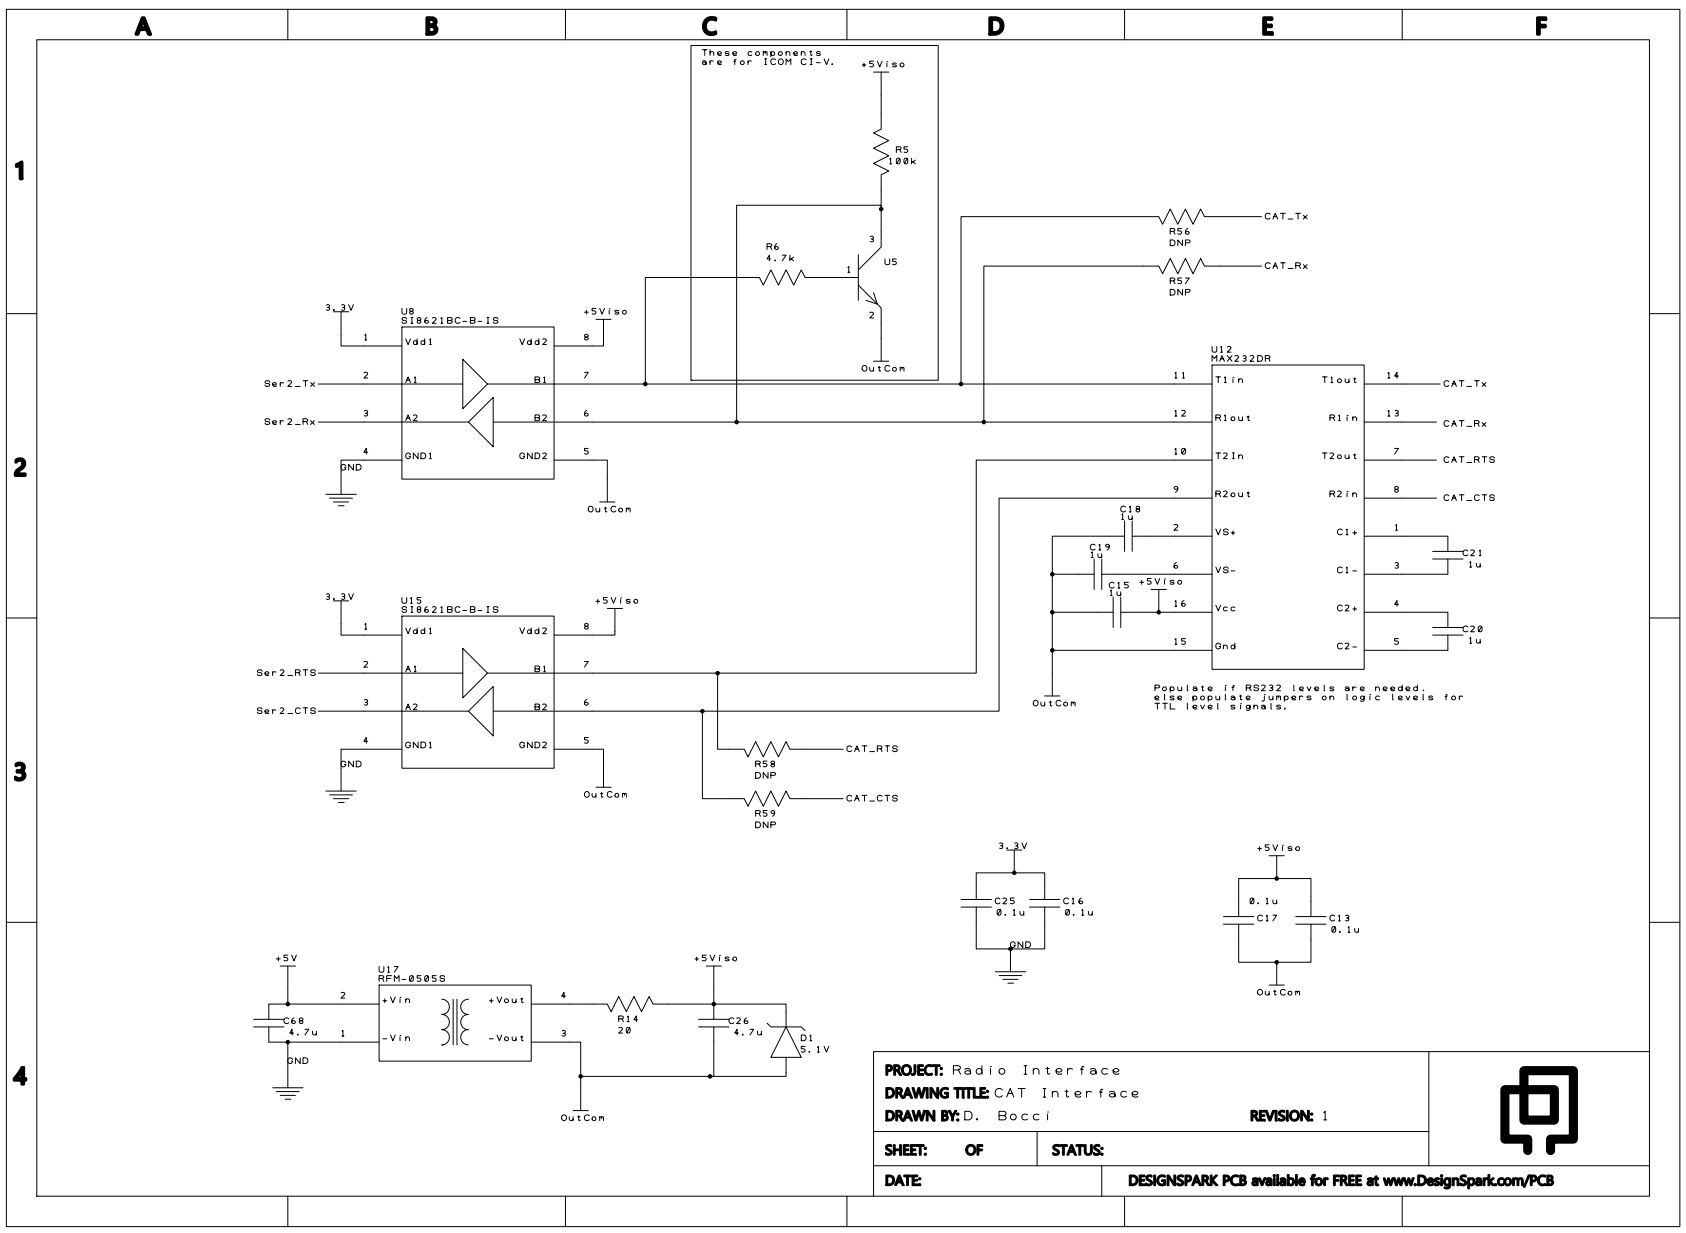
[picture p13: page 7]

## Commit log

2021-02-03 Initial PCB design
    [Audio.sch, Outputs.sch, Prototyping.sch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]
2021-02-05 almost done
    [Audio.sch, Outputs.sch, Prototyping.sch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]
2021-02-10 wrapping up PCB design
    [Audio.sch, CAT Interface.sch, Design Calculations.xlsx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]
2021-02-11 Adding gerbers and pdf of schematics, finalized for rev0 PCBs
    [Audio.sch, CAT Interface.sch, Outputs.sch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]
2021-03-17 Fixing up issues found from the rev 0 PCBs.
    [Audio.sch, CAT Interface.sch, Outputs.sch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]
2021-07-30 Adding pdf of PCB
